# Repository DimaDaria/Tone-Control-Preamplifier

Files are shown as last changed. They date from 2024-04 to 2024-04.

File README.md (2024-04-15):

# Tone-Control Preamplifier

 Utilized OrCAD to conduct simulations of the audio preamplifier circuit.
 
 Employed PCB Editor for the creation and preparation of boards for manufacturing purposes.

 Utilized GerbTools for visual analysis of boards, as well as for conducting Design Rules Checks and Design For Manufacture assessments.

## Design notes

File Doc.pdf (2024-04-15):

### Universitatea Politehnica din Bucuresti

## Facutatea de Electronică, Telecomunicații și Tehnologia Informației

# PREAMPLIFICATOR AUDIO CORECTOR DE TON

## Dima Daria-Elena

432A

## Prof. Coordonator: Florin Babarada

### PREAMPLIFICATOR AUDIO CORECTOR DE TON

În acest capitol este proiectat un preamplificator audio cu posibilitatea corecţiei frecvenţelor joase şi a celor înalte. Preamplificatorul audio corector de ton este compus din două etaje de amplificare conectate prin intermediul unei reţele de reacţie. Prin introducerea unor componente variabile în reţeaua de reacţie se pot amplifica sau atenua frecvenţele joase respectiv frecvenţele înalte.

### 3.1 TEMA DE PROIECTARE

Tema de proiectare se referă la proiectarea unui preamplificator audio corector de ton care să fie realizat cu tranzistoare bipolare. Corecţia de ton se referă la corecţia frecvenţelor joase şi anume a frecvenţelor mai mici ca 500Hz şi a frecvenţelor înalte respectiv mai mari ca 1KHz.
Etajul este compus din două amplificatoare, respectiv amplificatorul de intrare şi amplificatorul de ieşire, cuplate prin intermediul reţelei de reacţie de tipul RC. Reţeaua de reacţie este constituită din două filtre cu elemente pasive RC de joasă, respectiv înaltă frecvenţă în care anumite rezistenţe sunt variabile fapt ce permite amplificarea sau atenuarea frecvenţelor care sunt în banda de trecere a filtrelorRC. Amplificatorul de intrare şi cel de ieşire sunt alimentate din sursa de alimentare comună.

Figura 3.1-1. Schema bloc a preamplificatorului audio corector de ton

### 3.2 SETURI DE DATE DE INTRARE

Principalii parametri ai preamplificatorului audio corector de ton sunt:
- Rezistenţa de intrare Ri (KΩ)
- Rezistenţa de ieşire Ro (Ω)
- Corecţia minimă a frecvenţelor joase şi a frecvenţelor înalte ±20dB

Sursa de alimentare va asigura următorii parametri:
- Curentul nominal maxim I0M (mA)
- Rezistenţa de ieşire maximă R0M (Ω)
- Coeficientul de stabilizare S0

=

ΔV I
≥ S
ΔV0

0 min

- Tensiunea de alimentare este 220Vac ± 10%

Setul de date de intrare pentru proiectare
Nr. | Preamplificator corector de ton | Sursa de alimentare
Ri (MΩ) | Ro (Ω) | Av (-) | Aî,j (±dB) | I0M (mA) | R0M (Ω) | S0min (-)
2 | 2 | 150 | 5 | 18 | 10 | 4 | 3

### 3.3 SCHEMA ELECTRONICĂ

Conform schemei de principiu primul etaj este amplificatorul de intrare careasigură separarea reţelei de reacţie de etajele anterioare. În acest scop etajul de intrare este realizat cu tranzistorul T1 şi este de tip colector comun cu bootstrap la intrare asigurând o impedanţă mare de intrare şi mică de ieşire.
Reţeaua de reacţie este de tip RC cu elemente rezistive variabile P1 şi P2 care asigură reglarea frecvenţelor înalte şi joase.
Amplificatorul de ieşire este realizat cu tranzistoarele T2 şi T3 în conexiune emitor comun respectiv colector comun cuplate galvanic.
Primul etaj realizat cu T2 este destinat realizării unei amplificări de tensiune în buclă deschisă suficient de mare iar etajul realizat cu T3 este repetor pe emitor şi asigură o rezistenţă de ieşire mică. Cele două etaje realizează un amplificator inversor, astfel reţeaua de reacţie este plasată între intrarea şi ieşirea acestui amplificator de ieşire.

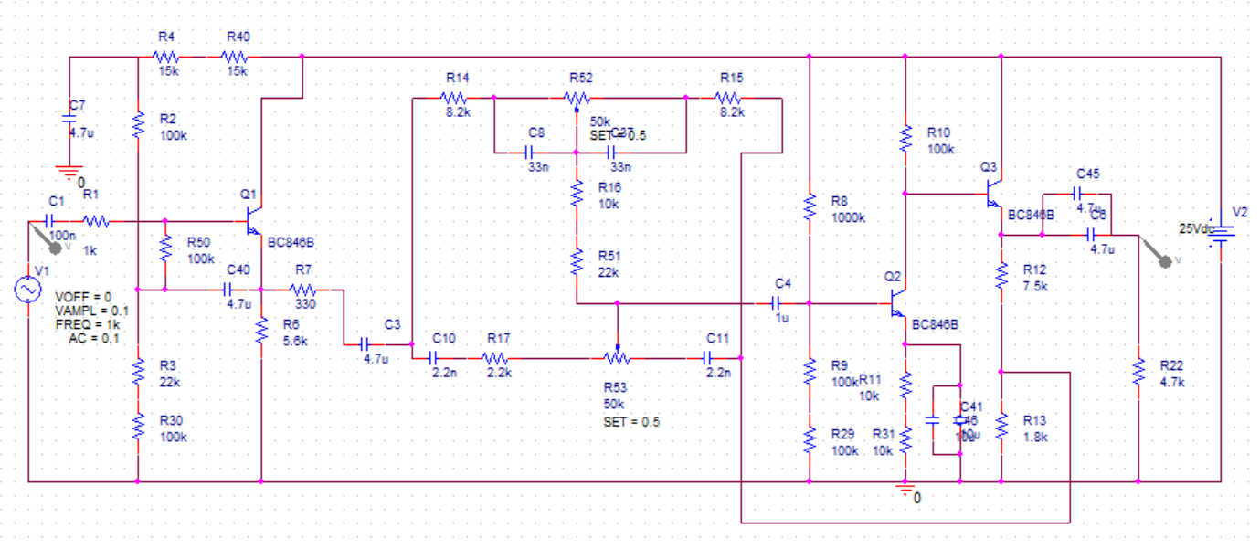
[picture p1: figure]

Figura 3.3-1. Schema electronică

### 3.4 DIMENSIONAREA REŢELEI DE REACŢIE

Elementele de atenuare pozitivă sau negativă pentru frecvenţele înalte respectiv joase formează reţeaua de reacţie negativă.
Pentru o bună înţelegere a principiului de funcţionare a corecţiei amplitudinii pe anumite domenii de frecvenţă considerăm etajele amplificatoare echivalente cu circuite operaţionale care au conectate impedanţele echivalente ca în Figura 3.4-1..

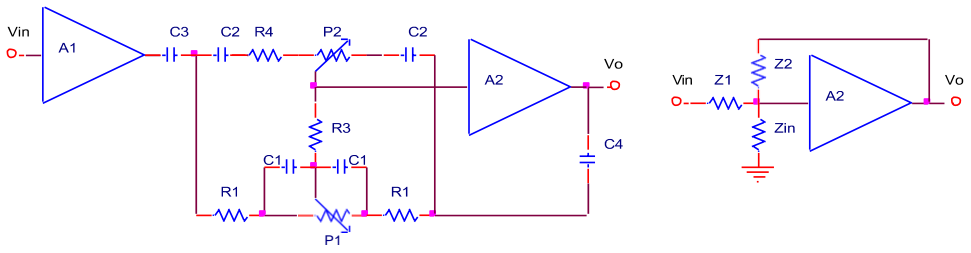
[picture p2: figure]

a) b)
Figura 3.4-1. Schema echivalentă a preamplificatorului audio corector de ton cu reţeaua de reacţie a) şi schema echivalentă simplificată b)

A1 reprezintă preamplificatorul de intrare iar A2 reprezintă amplificatorul de ieşire. Reţeaua de reacţie prevăzută cu potenţiometrele P1 şi P2 este desenată simplificat în Figura 3.4-2. b) amplificarea etajului fiind data de raportul impedanţelor Z 2
Z1
Calculul reţelei de reacţie se face pentru circuitele echivalente la joasă şi înaltă frecvenţă.

Circuitul echivalent pentru înaltă frecvenţă

C2 R4 | aP2 | (1-a)P2 | C2 | C2 R4 | aP2 | (1-a)P2 | C2

Figura 3.4-2. Circuitul echivalent al reţelei de reacţie pentru înaltă frecvenţă

Pentru înaltă frecvenţă circuitul echivalent este prezentat în Figura 3.4-2., iar funcţia de transfer este:

F(p) = Z 2 = k·

(1+ pt1)(1+ pt2)

Z1 (1 + pt3)(1 + pt4)

k = 1 | R1’ = R1 + 2R3
t1 = aR2C2 | t2 = [R1’ + (1-a)R2]C2
t3 = R1’C2 | t4 = R2C2

Curba de atenuare maximă se obţine pentru a = 0 şi rezultă:

t1 = 02 | t2 = [R1’ + R2]C2
t3 = (R1’+ aR2)C2 | t4 = (1-a)R2C2

Se alege P2 de 100KΩ.
Pentru ca interferenţa celor două circuite să fie minimă se impune ca R1<<P2 şi rezultă R1 ≤ 10KΩ.
R1’ s-a obţinut prin transformarea stelei R3, R1, R1 şi s-a neglijat rezistenţa ce apare între intrarea şi ieşirea lui A2, considerând că amplificatoarele A1 şi A2 au impedanţa de ieşire foarte mică.

Se alege f2 = 500Hz şi rezultă t2 = (R1’+R2)C2 = 3,2·10⁻⁴
s

Se alege f4 = 700Hz şi rezultă t4 = R2C2 ≈ 2,3·10⁻⁴
s

Rezultă şi se adoptă C2 = 2,2nF.

Se alege f3 = 1KHz şi rezultă t3 = R1’C2 = 1,6·10⁻⁴
s,
Þ R1’ = 72KΩ.

Punctul f3 = 1KHz s-a dedus grafic pe caracteristica Bode astfel încât atenuarea teoretică de –20dB se produce l
'

a
−

15KHz.
R R1
Se alege R1 = 8,2KΩ şi R3 =

1
2
Se adoptă R3 = 33KΩ.

= 31,9KΩ.

Curba de ridicare minimă se obţine pentru a = 1 şi rezultă:
t1 = R2C2 | t2 = R1’ C2
t3 = (R1’+R2)C2 | | t4 = R4C2

Curba de ridicare va fi simetrică cu cea de coborâre până la f4, când factorul de transfer devine constant.
Astfel, se explică rolul rezistenţei R4 care menţine al doilea pol din funcţia de transfer, chiar pentru a = 1 asigurându-se stabilitatea.
Se apreciază din considerente practice confirmate experimental că f4 ≈30Hz Þ t4

= (2·π·f4)

-1 = 5,3µ | Þ | R4 =

t4
= 2,4K
C2

Circuitul echivalent pentru joasă frecvenţă

C1 | C1
R1 | aP1 | (1-a)P1 | R1
Figura 3.4-3. Circuitul echivalent pentru joasă frecvenţă

Pentru circuitul echivalent la joasă frecvenţă funcţia de transfer are forma: F(p) = Z 2 = k·

(1+ pt1)(1+ pt2)

Z1 | (1 + pt3)(1 + pt4)
Se alege | P1 = nR1 = 100KΩ | Þ n ≈ 12

Curba de atenuare maximă se obţine pentru a = 0

Þ k =

1
,
1 + n
t1 = 0 | t2 = n·R1·C2
t3 = 0 | t4 =

n
·R1·C2
n + 1
Curba de ridicare maximă se obţine pentru a = 1 Þ k = n + 1,

t =

n
·R1·C1 | t2 = 0
1
n +1
t3 = n·R1·C1 | t4 = 0
Se alege | f2 = 50Hz | Þ | t2 = 3,2s
Þ | C1 ≈ t2 | = 32nF | Se adoptă C1 = 32nF.
| 12 R1
Reţeaua pentru joasă frecvenţă începe să lucreze sub frecvenţa de aproximativ 500Hz. La 50Hz ridicarea este de 20log(n +1)=22dB iar atenuarea de –22dB.

### 3.5 PROIECTAREA AMPLIFICATORULUI DE IEŞIRE

Amplificatorul de ieşire A2 este realizat cu T2 şi T3 iar pentru respectarea condiţiei de semnal mic trebuie ca semnalele alternative să fie mult mai mici ca tensiunea de alimentare. O tensiune de alimentare mare implică şi rezistenţe de polarizare de valori mari şi deci impedanţă mare de intrare. Din aceste considerente se alege Ec = 25V stabilizată. Distorsiunile se vor măsura experimental şi se va modifica PSFul dacă este cazul.

1. Se alege PSFul pentru tranzistorul T2

Curentul de colector ICT2 =0,1mA şi tensiunea colector-emitor VCE2 ≥ 10V

Se alege raportul

R10
≈ 10

R11

Se alege VR10 ≈ 10V | Þ | Se adoptă R10 = 100KΩ şi R11 =20 KΩ
2. Se alege PSFul pentru tranzistorul T3

Curentul de colector ICT3 =1,5mA şi tensiunea colector-emitor VCE3 = 10V

Þ R12 + R13 ≈

EC − VCE3

IC 3

=

15V
= 10KΩ
1,5mA
3. Alegerea tranzistoarelor

Se aleg tranzistoarele de tip BC109C cu următoarele valori limită absolute: VCE0 =25V
Ptot = 300mW

IC = 100mA
Tj = 175°C

IB = 50mA

şi caracteristicile statice:
h21E = 270 | VCEsat < 0,2V | VBEsat < 0,8V
4. Dimensionarea rezistenţelor R12, R13

IB,T3=

IC ,T 3

h21E

=

1,5mA
= 5,5µA
270

Acest curent poate fi neglijat în raport cu IC2. În acest caz tensiunea pe R10 este: VR10 = R10 · IC2 = 100K · 0,1mA = 10V
Þ VR12+R13 = EC – VR10 – VBE2 = 25 – 10 - 0,6 = 14,4V
În reţeaua de reacţie s-a neglijat rezistenţa care apare între intrarea şi ieşirea amplificatorului de ieşire A2. Valoarea acestei rezistenţe este:
R

2 + 2· R · R
Rp = | 1 | 1 | 3 ≈ 18KΩ >> R0,A2
R3
Se alege R13 = 1,8KΩ şi se calculează R12:

R12 + R13 =

V R12+R13

| | | = 14,4V = 9,3KΩ
| | IC 3 | 1,5mA
Þ | R12 = 9,3KΩ - 1,8KΩ = 7,5KΩ.
5. Calculul divizorului de bază pentru tranzistorul T2

Curentul prin divizorul de polarizare a bazei tranzistorului T2 este:
IB2 = | IC 2
=

0,1mA
| | | = 0,37µA
| h21E | 270

Deoarece impedanţa de intrare a amplificatorului A2 este dată de impedanţa de intrare în T2, iar aceasta este aproximativ R9, se alege R9 = 200KΩ.
Tensiunea pe rezistenţa R9 poate fi exprimată astfel:
VR9 = VR11 +VBE2 = 20KΩ · 0,1mA + 0,6V = 2,6V
Þ R9 R8 + R9
=

V R9 =
EC

2,6V
25V

≈ 0,1

Þ R8 ≈ 8R9 = 1,6MΩ

6. Calculul impedanţei de intrare în A2

Parametri dinamici ai tranzistorului T2 sunt:

| gm2 = 40 · IC2 = 40 · 0,1 = 4mA/V

h11e,T2

β
=
gm 2

=

270
4

= 67,5KΩ

Impedanţa de intrare în T2 este:

Zin, T2 = h11e,T2 + h21e,T2 · R11 = 67,5 KΩ + 270 · 20KΩ ≈ 5,4MΩ

Impedanţa de intrare în T2 este:

Zin, A2 = ( R9 || R8 ) || Zin, T2 ≈ 180KΩ || 5,4MΩ ≈ 180KΩ Această valoare este suficient de mare.

7. Amplificarea în buclă deschisă a etajului realizat cu T2

Atenuarea maximă a circuitului este de aproximativ 10 şi se verifică ca amplificarea fără reacţie să fie suficient de mare:

Av ≈ Av,T2 =

h21E · RS 2

Rg + h11e2

RS2 este rezistenţa de sarcină a tranzistorului T2:

RS2 = R10 || Zin, T3

Zin, T3 = h11e3 + h21e3 (R12 +R13) =

Þ RS2 ≈ R10 = 100KΩ

270
40·1,5mA

+ 270 · 9,3KΩ ≈ 2,5MΩ

Þ Av ≈ Av,T2 =

270 ·100KΩ

80KΩ

= 338 valoare suficient de mare.

8. Amplificarea în buclă închisă

În poziţia mediană a lui P1 şi P2 se obţine Z1 = Z2, iar amplificarea este:

é

C5 êR11
ë

Rg + h11e2

ù

h21e2

ú
û

Avr ≈

1
=
β r

R12+ R13 =

R13

7,5+1,8
1,8 = 5,17 ≈ 5

Micşorarea amplificării este compensată de îmbunătăţirea răspunsului tranzitoriu.

9. Dimensionarea condensatorului C5

C5 formează un pol şi un zero, polul fiind plasat la frecvenţă mai mare.

ω5 =

1

Pentru tranzistorul T2, considerăm pentru uşurinţa calculelor parametri dinamici aproximativi h11e2 ≈ 100KΩ şi h21e2 ≈ 100.
Din motive de stabilitate se alege polul dat de C5 polul dominant al schemei şi anume f5=10Kz.

Þ C5=
2π f

1

h11e2

5

= 15,9µF

h21e2
Se adoptă C5 = 16µF/10V
10. Dimensionarea condensatorului C4

Tot din considerente de stabilitate, se alege polul dat de C4 la o frecvenţă mult mai mică decât cea dată de C5. Se alege f4 = 1Hz << 10Hz = f5.
Þ C4 =

1
=

1
= 0,88µF
2π f
4
- Zin, A2 2 · π ·1·180K

Se alege C4 = 1µF.

### 3.6 PROIECTAREA AMPLIFICATORULUI DE INTRARE

Amplificatorul de intrare este constituit din etajul repetor pe emitor cu bootstrap la intrare realizat cu tranzistorul T1.

1. Stabilirea PSFului

Se alege IC1 = 2mA care este o valoare relativ mare din punct de vedere al zgomotului, dar care asigură curent de bază suficient de mare pentru a fi insensibil la curentul de fugă prin capacitatea de bootstrap C2.
Se alege VCE1 ≈ VR6.
Cunoaştem R6 şi IC1 | Þ | VR6 = 5,6KΩ · 2mA = 11,2V

·

VCE1 = EC - VR6 = 13,8V

2. Dimensionarea rezistenţei R5

Tensiunea în baza tranzistorului T1 este:
VBT1 = VBE1 + VR6 = 0,6 + 11,2 = 11,8V Curentul de bază al tranzistorului T1 este:

IBT1 =

IC1
=

2
= 5µA
h21E1 400

Din catalog pentru IC1 = 2mA şi VCE1 = 14V se obţine h11e1 ≈ 10KΩ. Se impune R5 >> h11e1 şi se alege R5 = 100KΩ.
VR5 = R5 · IB1 = 100KΩ · 5µA = 0,5V
VR3 = VB1 + VR5 = 11,8 + 0,5 = 12,3V
3. Calculul divizorului de bază

Se alege Id = 20 · IB1 = 100µA Þ R2 + R3 + R4 =

EC
= 25V = 250KΩ
I d | 100µA
Þ | R3 =

V R3
·(R + R + R ) =

12,3V
- 250KΩ = 123KΩ
2 | 3 | 4
EC | 25V
Se adoptă R3 = 120KΩ.
Pentru a avea o valoare convenabilă a condensatorului de filtraj C7 se alege R4 = 30KΩ şi Þ R2 = 100KΩ.
4. Dimensionarea condensatorului de filtraj C7

Rezistenţa R4 şi condensatorul C7 decuplează alimentarea circuitului de bază. Pentru o bună decuplare f7 << frecvenţa inferioară limită a benzii.
Pentru C7 = 22µF se obţine f7 =

1

2π C7 R4

= 0,24Hz

5. Impedanţa de intrare

Impedanţa de intrare în amplificatorul de intrare şi în preamplificatorul corector de ton este:
Zin = R5 || h11e1 + (β

’ + 1) · R6

β

’ = β1 ·

R5

R5 + h11e1

100KΩ
= 400 ·
100KΩ +10KΩ

= 360

Þ Zin = 9,1 KΩ +360 · 5,6KΩ = 2MΩ

Z g + (RS h11e1)

β

' +1

15KΩ + 9KΩ
360

48KΩ +10KΩ
400
6. Dimensionarea condensatoarelor C1, C2

Condensatoarele C1 şi C2 se dimensionează pentru frecvenţe mai mici ca 1Hz. Se alege C1 = 0,1µF şi se obţine f1 =

1

2π C1Zin

= 0,79Hz

Pentru C2 se alege f2 = 0,5Hz şi se obţine C2 =

Se adoptă C2 = 4,7µF

1
2π f 2R5

= 3,2µF

7. Impedanţa de ieşire a amplificatorului de intrare
| Z0,A1 ≅ | R6

Se apreciază că impedanţa generatorului este mai mică decât 15KΩ şi pentru cazul cel mai defavorabil se ia Zg = 15KΩ.

Þ | Z0,A1 ≅ | 5,6KΩ ≈ 6,6Ω

Se verifică condiţia Z0,A1 = 6,6Ω << Rp = 18KΩ

8. Impedanţa de ieşire a preamplificatorului corector de ton

Z0, pct =

Zg + h11e3

h21e3

(R12 + R13)

Zg = R10 ||

1
= 100KΩ || 92KΩ = 48KΩ

h22e2

Considerăm pentru T3 parametri dinamici următori: h11e3 = 10KΩ şi h21e3 = 400

Þ | Z0, pct = | 9,3KΩ = 143Ω
9. Dimensionarea potenţiometrului de volum

Se poate face dimensionarea potenţiometrului de volum utilizând condiţia:

Z0, pct << Pv << Zin, AP
Impedanţa de intrare în amplificatorul audio de putere Zin, AP ≈ 39KΩ

Raportul impedanţelor limită este k =

Zin, AP

Z 0, pct

39KΩ
=
143Ω

≈ 270

Se aproximează PV ≈ | 0, pct

Se adoptă PV = 2,5KΩ

- Z =

Zin, AP
= 2,37KΩ
10. Dimensionarea condensatorului C6

Din motive de stabilitate respectiv dispersarea constantelor de timp la frecvenţe joase se alege f6 ≅ 3Hz. Rezultă:
C6 =

1

2π f 6 PV

= 21µF

Se adoptă C6 = 22µF/25V.

### 3.7 SIMULAREA CORECTORULUI DE TON

Pentru început s-a efectuat simularea PSFului pentru întregul circuitpreamplificator audio corector de ton.
Deoarece în schema electronică a fost utilizat R8 = 1MΩ în loc de 1,6MΩ curentul de colector al tranzistorului T2 este de IC,T2 = 0,17mA în loc de =0,1mA cum fusese proiectat, dar diferenţa nu este mare. Principalele tensiuni şi curenţi din circuit sunt prezentate în Figura 3.7-1..
La simularea răspunsului tranzitoriu prezentat în Figura 3.7-2. s-a utilizat o sursă de semnal V1 cu amplitudinea de 0,1V şi frecvenţa de 1KHz. Semnalul la ieşirea corectorului de ton este defazat cu 180° şi amplificat de 5 ori pentru P1 şi P2 pe poziţii de mijloc.

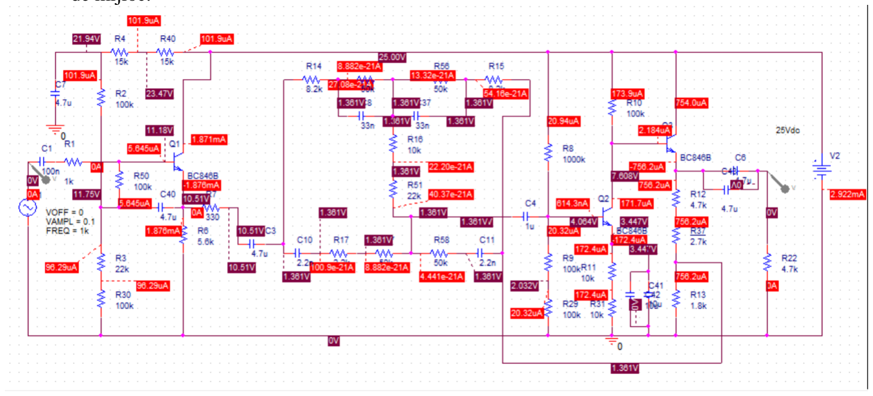
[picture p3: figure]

Figura 3.7-1. Simularea PSF-ului circuitului corector de ton

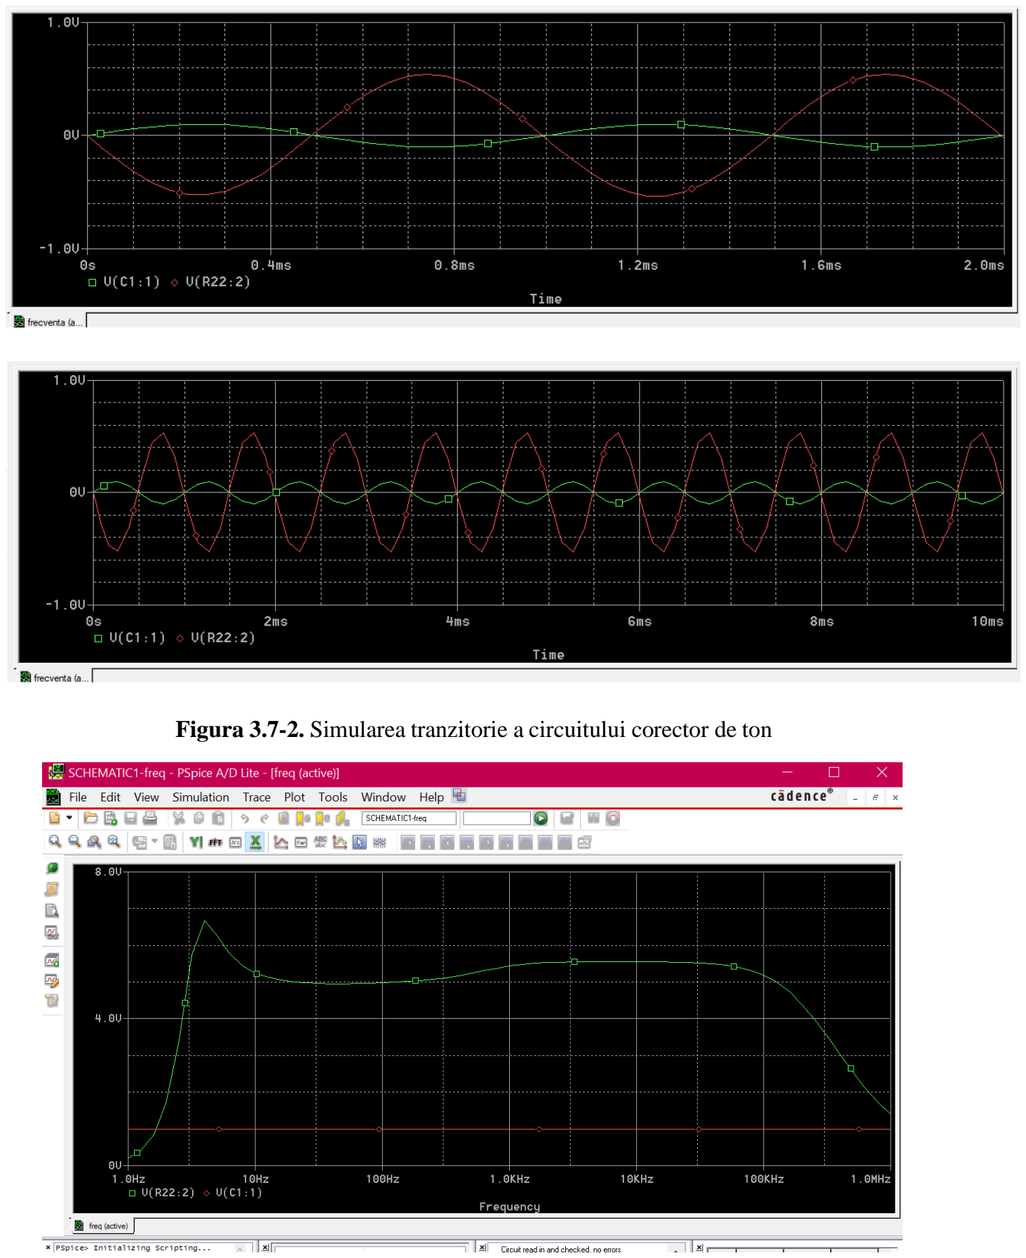
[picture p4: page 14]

Figura 3.7-2. Simularea tranzitorie a circuitului corector de ton

Figura 3.7-3. Simularea răspunsului în frecvenţă al corectorului de ton cu P1 şi P2 pe poziţia mediană (R55=50KΩ, R56=50KΩ şi R57=50KΩ, R58=50KΩ)

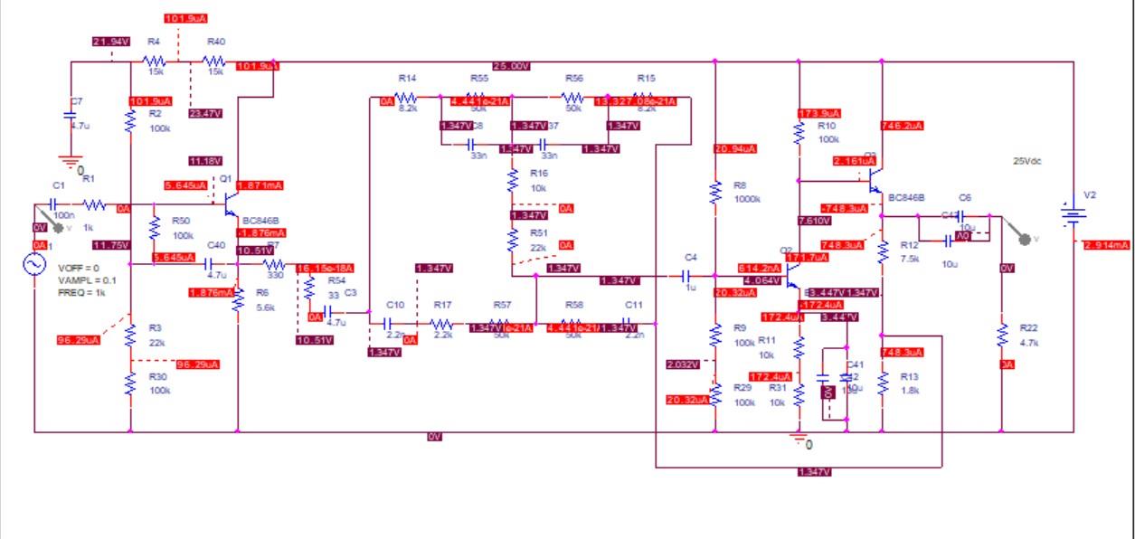
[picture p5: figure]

Simularea răspunsului în frecvenţă pentru P1 şi P2 pe poziţii de mijloc Figura 3.7-
3. ne arată o amplificare de 5 la o amplitudine a semnalului de 0,1V şi răspuns uniform în banda de frecvenţe cu excepţia frecvenţelor joase unde este practic realizată o corecţie fiziologică.
Simulările 3.7-4. ÷ 3.7-7. arată accentuarea şi atenuarea frecvenţelor joase şi a celor înalte cu aproximativ ±20dB faţă de poziţia mediană de la 0,5V.

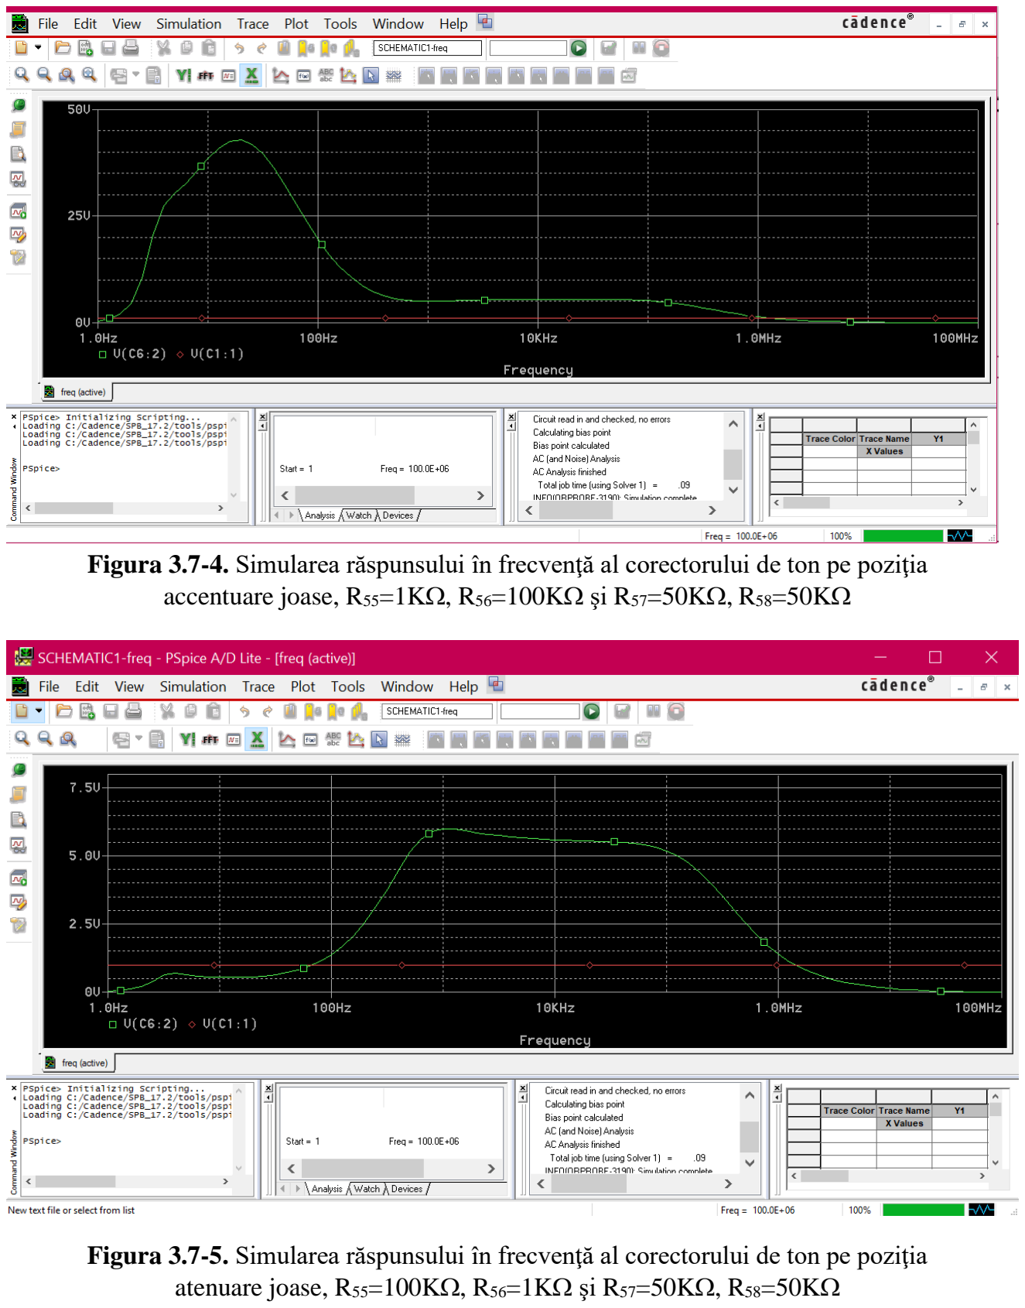
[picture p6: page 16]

Figura 3.7-4. Simularea răspunsului în frecvenţă al corectorului de ton pe poziţia accentuare joase, R55=1KΩ, R56=100KΩ şi R57=50KΩ, R58=50KΩ

Figura 3.7-5. Simularea răspunsului în frecvenţă al corectorului de ton pe poziţia atenuare joase, R55=100KΩ, R56=1KΩ şi R57=50KΩ, R58=50KΩ

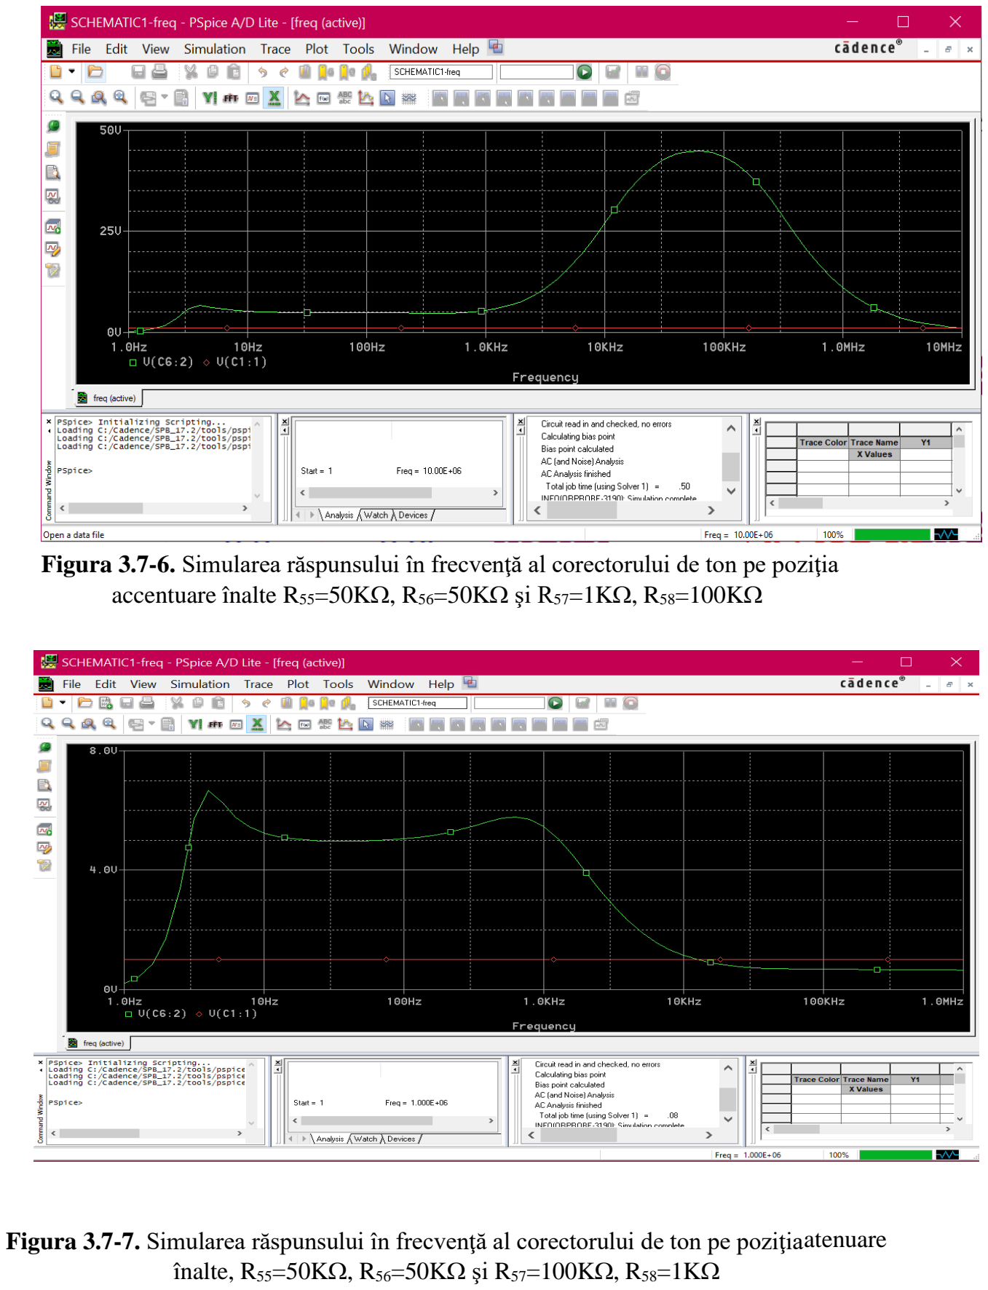
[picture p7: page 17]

Figura 3.7-6. Simularea răspunsului în frecvenţă al corectorului de ton pe poziţia accentuare înalte R55=50KΩ, R56=50KΩ şi R57=1KΩ, R58=100KΩ

Figura 3.7-7. Simularea răspunsului în frecvenţă al corectorului de ton pe poziţiaatenuare înalte, R55=50KΩ, R56=50KΩ şi R57=100KΩ, R58=1KΩ

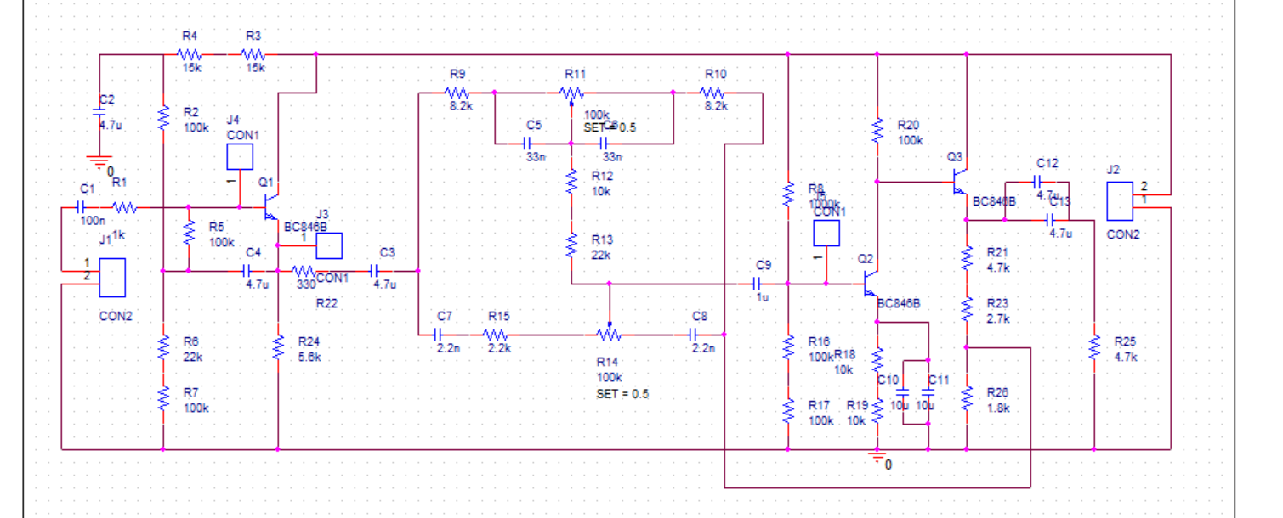
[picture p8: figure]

Figura 4 – Schematic pentru export in PCB Editor

LISTA COMPONENTELOR - BOM

Item | Quantity Reference | Part
______________________________________________
1 | 1 C1 | 100n
2 | 5 C2,C3,C4,C12,C13 | 4.7u
3 | 2 C5,C6 | 33n
4 | 2 C7,C8 | 2.2n
5 | 1 C9 | 1u
6 | 2 C10,C11 | 10u
7 | 2 J1,J2 | CON2
8 | 3 J3,J4,J5 | CON1
9 | 3 Q1,Q2,Q3 | BC846B
10 | 1 R1 | 1k
11 | 8 R2,R5,R7,R11,R14,R16,R17,R20 | 100k
12 | 2 R3,R4 | 15k
13 | 2 R6,R13 | 22k
14 | 1 R8 | 1000k
15 | 2 R9,R10 | 8.2k
16 | 3 R12,R18,R19 | 10k
17 | 1 R15 | 2.2k
18 | 2 R21,R25 | 4.7k
19 | 1 R22 | 330
20 | 1 R23 | 2.7k
21 | 1 R24 | 5.6k
22 | 1 R26 | 1.8k

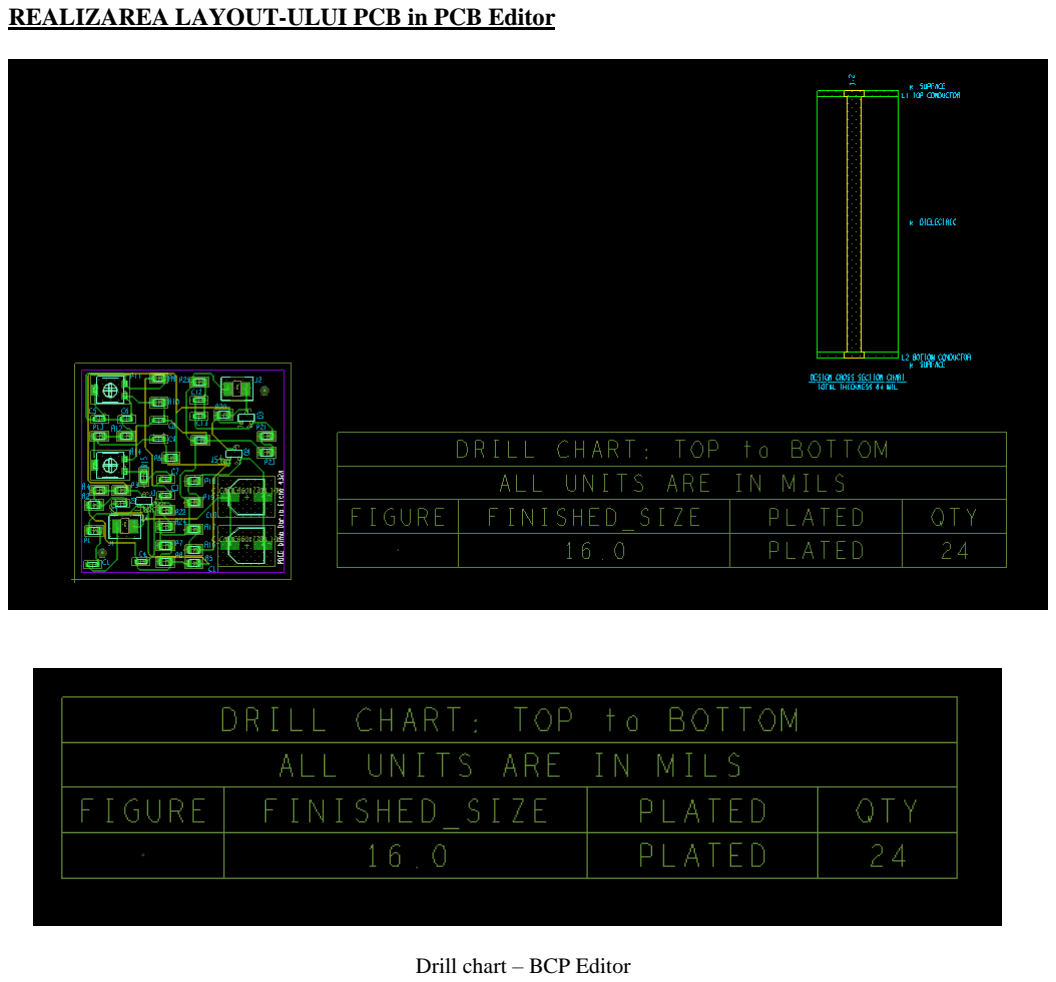
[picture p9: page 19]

REALIZAREA LAYOUT-ULUI PCB in PCB Editor

Drill chart – BCP Editor

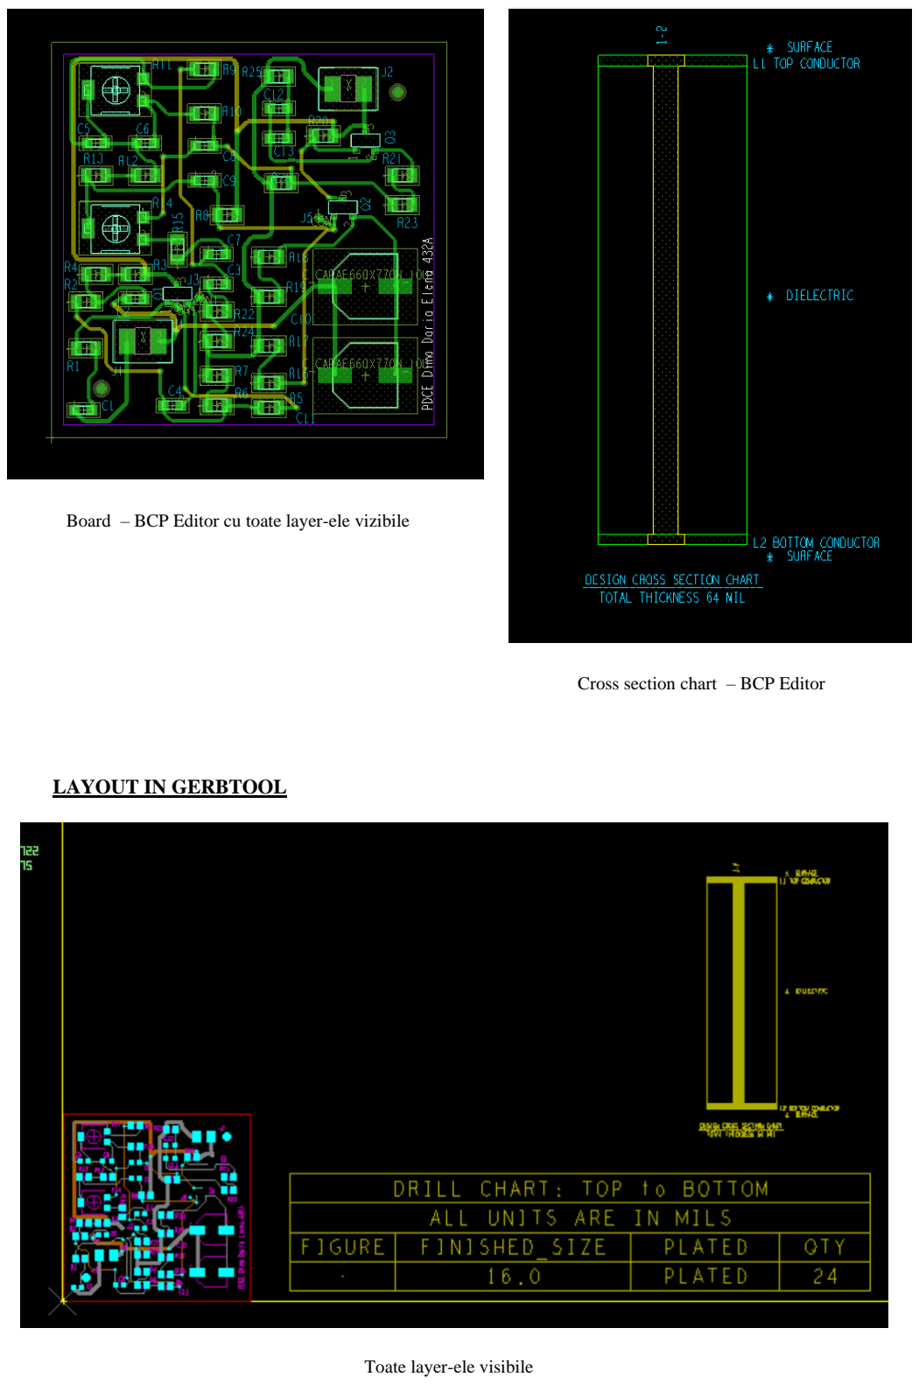
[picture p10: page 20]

LAYOUT IN GERBTOOL

Board – BCP Editor cu toate layer-ele vizibile

Cross section chart – BCP Editor

Toate layer-ele visibile

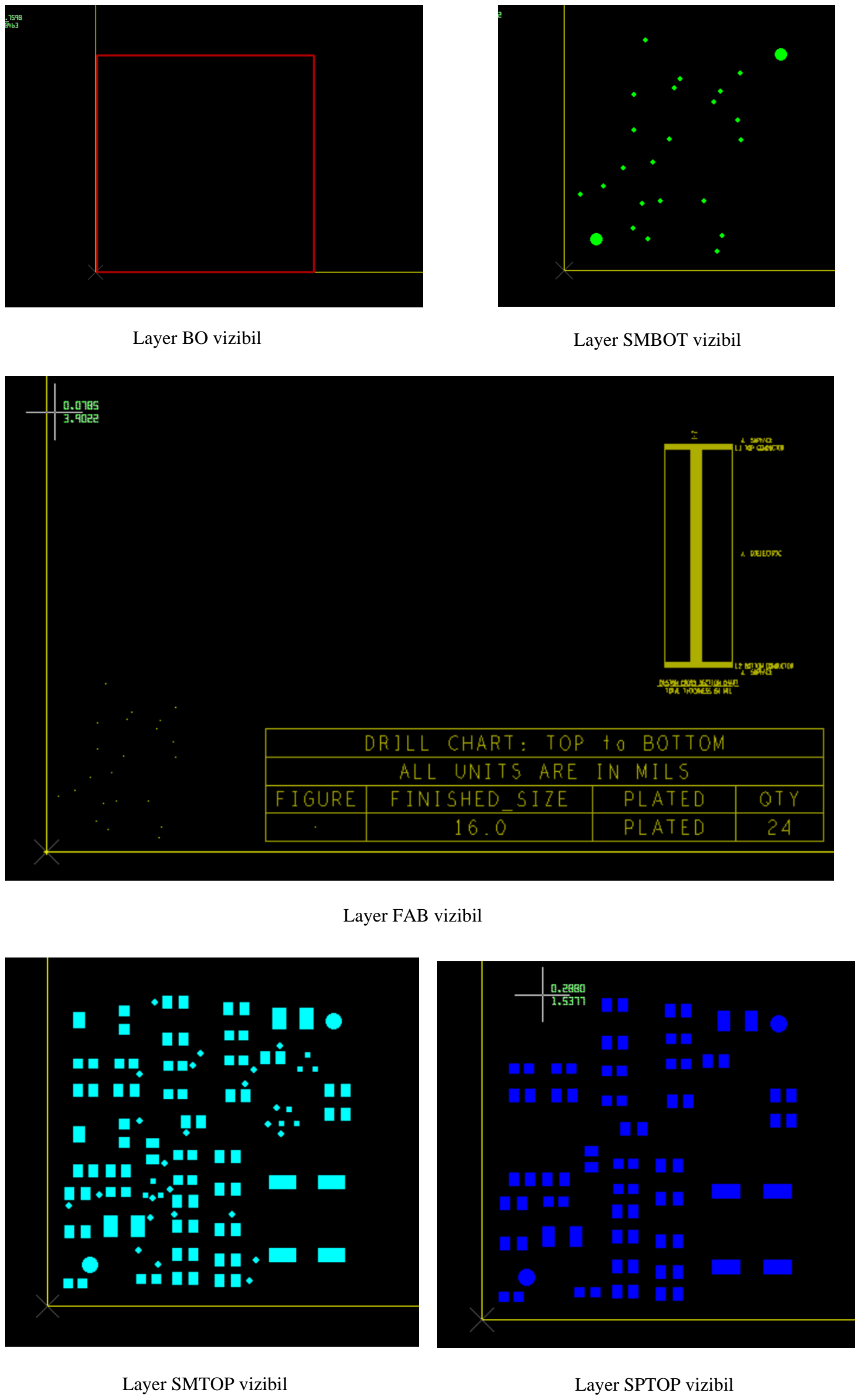
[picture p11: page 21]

Layer BO vizibil | Layer SMBOT vizibil

Layer FAB vizibil

Layer SMTOP vizibil | Layer SPTOP vizibil

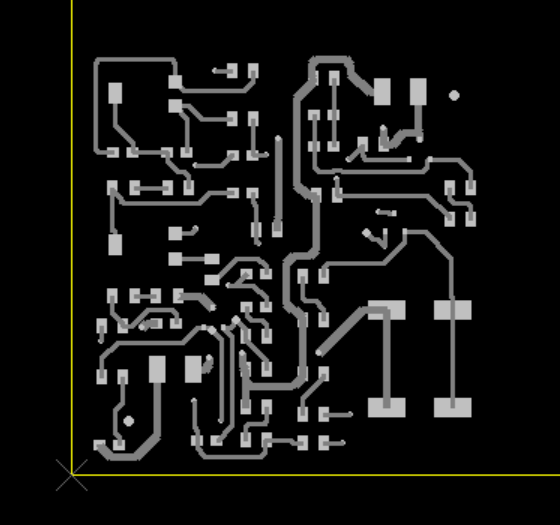
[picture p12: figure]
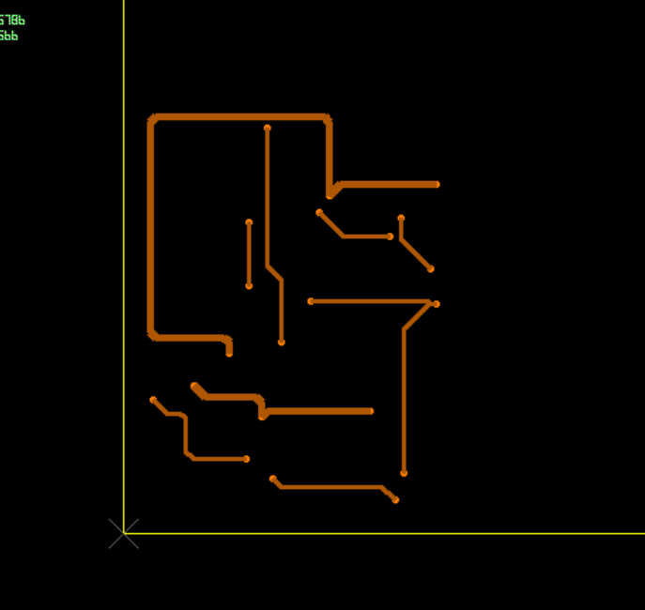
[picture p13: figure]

Layer BOTTOM vizibil | Layer TOP vizibil

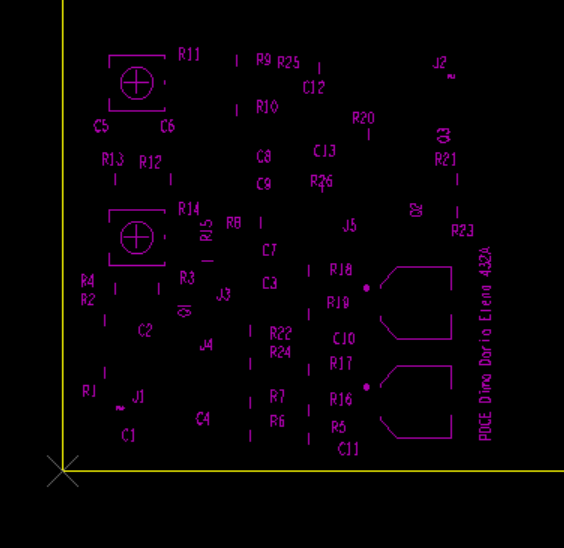
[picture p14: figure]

Layer SSTOP vizibil

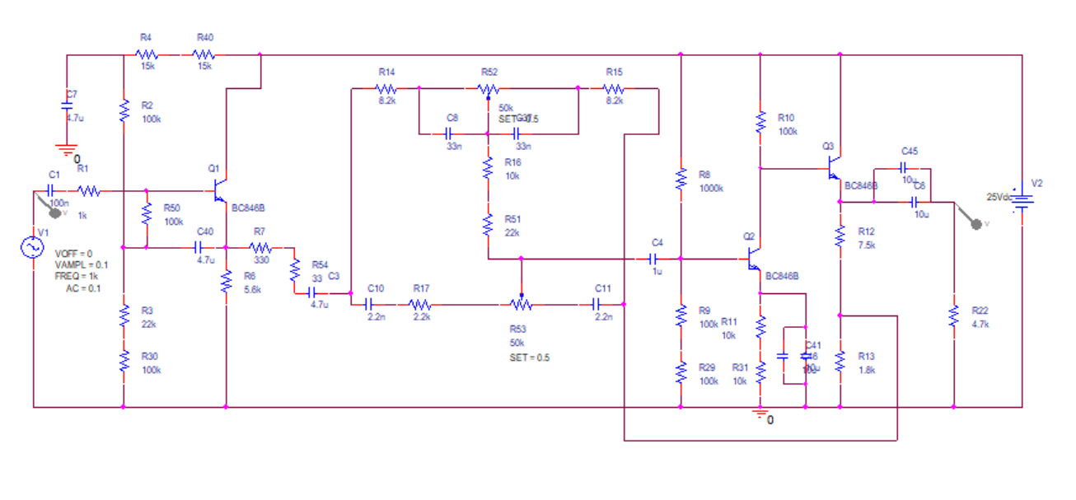
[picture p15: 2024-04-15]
Schema electrica.PNG

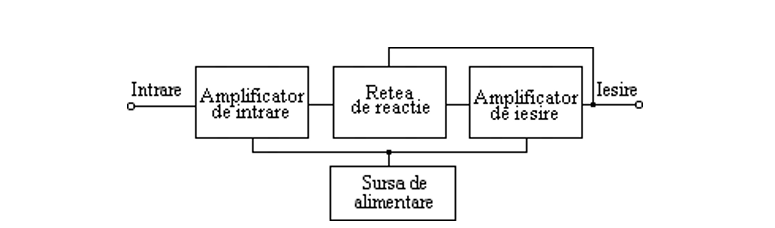
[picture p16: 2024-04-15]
Schema bloc.PNG

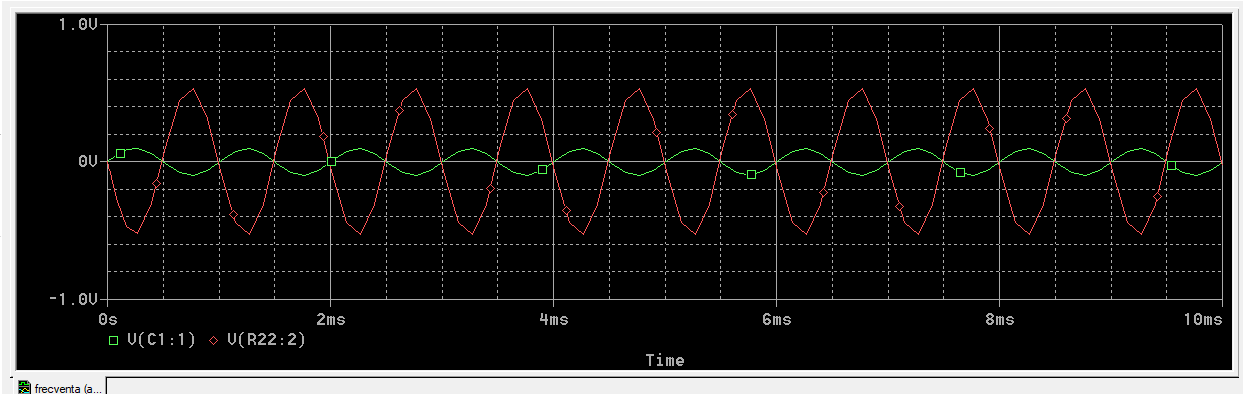
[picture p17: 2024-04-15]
Simulations/tran1.png

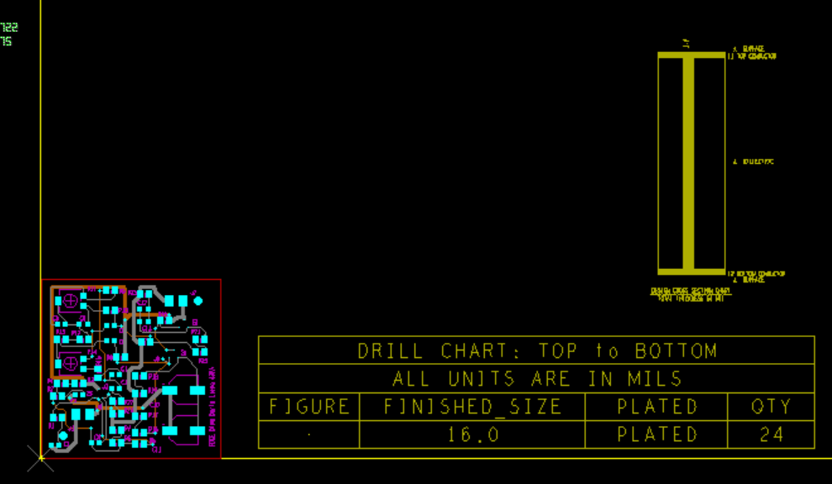
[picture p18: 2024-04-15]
Layout/ALL LAYERS 1.PNG

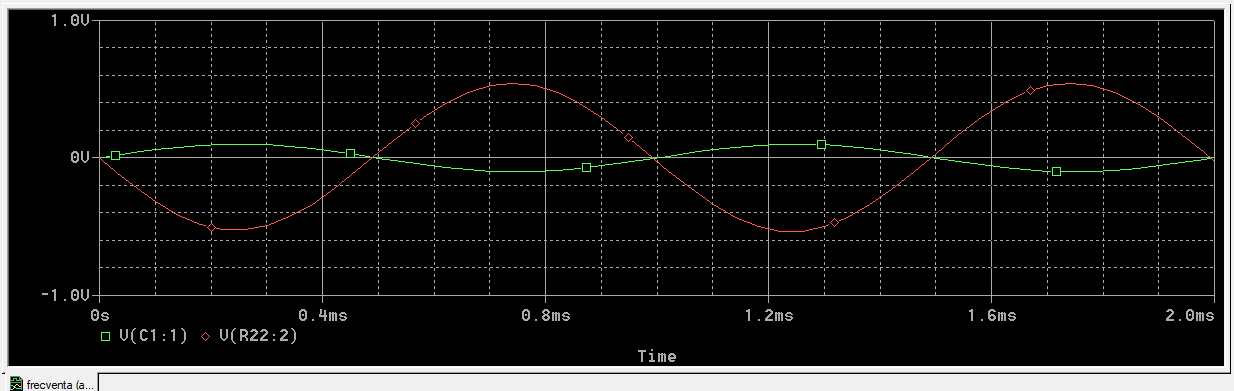
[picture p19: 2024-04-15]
Simulations/tran2.png

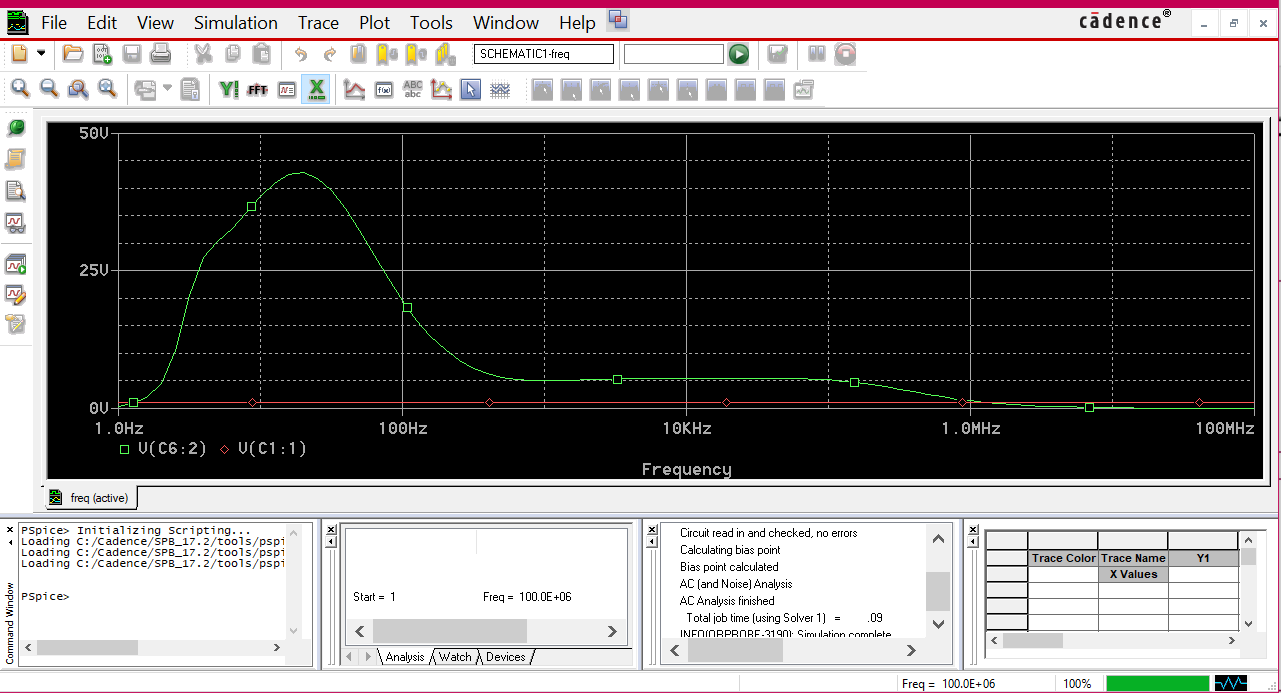
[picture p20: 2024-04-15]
Simulations/simulare_frecventa_pozitie_accentuate_joase_1.PNG

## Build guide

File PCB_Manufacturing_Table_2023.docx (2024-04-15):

General info document for PCB manufacturing
No. | Item Name | File Name | | | | | | Info / Remarks / Notes
| BOARD
1 | Board Name / Number | PACT_DDE432A | | | | | | -
2 | Revision Date | 16 January 2024 | | | | | | -
3 | Board Size | 40 x 40 mm² | | | | | | -
4 | Board Quantity | 1 | | | | | | -
5 | Material / Dielectric Type | FR-4 | | | | | | -
6 | Board Thickness | 1.6 mm | | | | | | -
7 | Copper Thickness | 35 μm | | | | | | -
| LAYERS
8 | Number of Electrical Layers | 2 | | | | | | -
9 | Copper Layer TOP | TOP.art | | | | | | -
10 | Copper Layer BOTTOM | BOTTOM.art | | | | | | -
11 | Copper GND Plane | - | | | | | | -
12 | Copper PWR Plane | - | | | | | | -
13 | Copper INNER 1 | - | | | | | | -
14 | Copper INNER 2 | - | | | | | | -
15 | Solder Mask TOP | SMTOP.art | | | | | | -
16 | Solder Mask BOTTOM | SMBOT.art | | | | | | -
17 | Solder Paste TOP | SPTOP.art | | | | | | -
18 | Solder Paste BOTTOM | - | | | | | | -
19 | Peelable Mask TOP | - | | | | | | -
20 | Peelable Mask BOTTOM | - | | | | | | -
21 | Silk Screen TOP | SSTOP.art | | | | | | -
22 | Silk Screen BOTTOM | - | | | | | | -
23 | Board Outline | included on all layers | | | | | | -
24 | Fabrication Drawing | - | | | | | | -
| MILLING & DRILLING
25 | Mill Drawing | - | | | | | | -
26 | Drill Drawing | Included in FAB.art | | | | | | -
27 | N.C. Drill (for both PH & NPH) | - | | | | | | -
28 | N.C. Drill / Plated Holes (PH) | 24 | | | | | | -
29 | N.C. Drill / Non-Plated Holes (PH) | - | | | | | | -
| FINISHING
30 | Panelisation | - | | | | | | -
31 | Electrical Test | - | | | | | | -
32 | Copper Finishing | x | HASL | | OSP | | | ENIG
33 | Board Outline Machining | | Routing | | Milling | | x | V-Cutting
34 | Final remarks | - | | | | -

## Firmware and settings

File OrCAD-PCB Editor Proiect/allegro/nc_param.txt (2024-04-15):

INTEGER-PLACES         2
DECIMAL-PLACES         5
X-OFFSET               0.000000
Y-OFFSET               0.000000
FEEDRATE               1
COORDINATES            ABSOLUTE
OUTPUT-UNITS           ENGLISH
TOOL-ORDER             INCREASING
REPEAT-CODES           YES
SUPPRESS-LEAD-ZEROES   YES
SUPPRESS-TRAIL-ZEROES  NO
SUPPRESS-EQUAL         YES
TOOL-SELECT            YES
OPTIMIZE_DRILLING      NO
ENHANCED_EXCELLON      YES
TAPE-FILE              C:/Users/daria/OneDrive/Desktop/ETAPA 1 P1/Etapa 2 - OrCAD-PCB Editor/allegro/DRILL.drl
HEADER                 none
LEADER                 12
CODE                   ASCII
SEPARATE               NO
SEPARATE-ROUTING       NO
DRILLING               LAYER-PAIR
BACKDRILL              NO
CAVITY                 NO
COUNTER                NO
TOLERANCE_DRILL        YES
TOLERANCE_TRAVEL       YES
TOOL_SIZE              YES
ROTATION               YES
NON_STANDARD           YES
TOTAL_DRILL            NO
SEPARATE_SLOT          NO
SUPPRESS_TOLERANCE     YES
SUPPRESS_TOOLSIZE      YES
SUPPRESS_ROTATION      YES
